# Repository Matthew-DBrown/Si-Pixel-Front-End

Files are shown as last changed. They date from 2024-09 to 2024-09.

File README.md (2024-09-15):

# Si-Pixel-Front-End
A pulse shaping front-end from discrete, off-the-shelf components for a diode acting as a pixel for particle detection. 
The front-end circuit alone is considered here.

This project project investigates the feasibility of using a diode as a pixel, where its depletion width is the active region where particles may interact, such as cosmic rays.
The output from the diode is expected to be a sharp current pulse that needs to be shaped to be digitally counted. This calls for the design of a front-end pulse shaping circuit for which the KiCad files and outputs can be seen in this project.

Included files:
- KiCad Schematics
- PCB Layout (future proposals)
- Breaboard and waveform images

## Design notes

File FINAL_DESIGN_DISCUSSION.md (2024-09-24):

## Analogue Front-End Components
### Integration and Initial Shaping

The first stage of the analogue front end is to integrate the input charge with an active integrator. As established, the input signal must be amplified, and the integrator can achieve this
with RC values less than unity, according to,

$` V_{\text{out}} = -\frac{1}{RC}\int V_{\text{in}}\,dt`$.

The input charge will be proportional to
the energy of the detected particle, hence the integrator’s importance in particle identification.
The choice of capacitance is informed by the total charge injected from the simulated imput pulse. The
current can be obtained by dividing the equation of the simulated input,

$` V_{in}(t) = A\left\{\exp\left(-\frac{t}{\tau_1}\right) - \exp\left(-\frac{t}{\tau_2}\right)\right\}. `$,

with the resistance through which the the pulse will travel after being emitted by the diode. To generate the simulated pulse in reality, a test capacitor will have to discharge through a resistor to create the exponential envelope desired. An arbitrary value resistance is chose here, at 18 Ω, and the simulated pulse is apprxoimately 100 ns in duration as seen in the theory file. The charge injected into the circuit can be estimated by integrating the current over the pulse width, T = 100 ns,

$` Q_{\text{tot}} = \frac{1}{R}\int_{0}^{T} V_{\text{in}}\,dt\approx92\times10^{-15}\, \text{C} `$.

The op-amps and buffers discussed in the desin considerations operate at ±5 V which is therefore the
maximum output magnitude of the integrator. A small voltage drop would be seen such that
the true maximum output is slightly less, hence the capacitor value is chosen from Q/V , with
V slightly below 5 V. This means using a small ~25 ×10−15 F capacitor would be favourable,
with SMD models meeting this criteria. The small capacitance results in a short time constant,
meaning the integration is performed rapidly, creating a step-like output at the integrator.

To set the pulse width after the integrator, a high-pass CR filter follows, isolated by a buffer.
A decay constant is introduced, such that the pulse width is reduced to approximately five time
constants (where one time constant, τ is 320 ns in this design) of the CR filter, assuming that
the integration time is negligible [^1]. The integrator’s capacitor must fully discharge before another pulse from the diode arrives, since any remaining charge will introduce an offset on the integrated pulse and hence the output, providing artificially high voltages, and false particle identification. Placing a resistor in parallel with the integrating capacitor provides a controlled discharge path. It must have sufficiently large resistance such that on the time scale of the input pulse, the decay of the capacitor is negligible, and remains to appear step-like.

For the same reasons discussed in the theory section, the profile of the high-pass filter output is not
practical since the maximum amplitude is sharp and short in duration after introducing a decay
tail to the step input from the integrator. A low-pass filter is therefore introduced, with the
same time constant as the high-pass filter; these stages in addition to their outputs are illustrated below along with their Fourier transforms. 

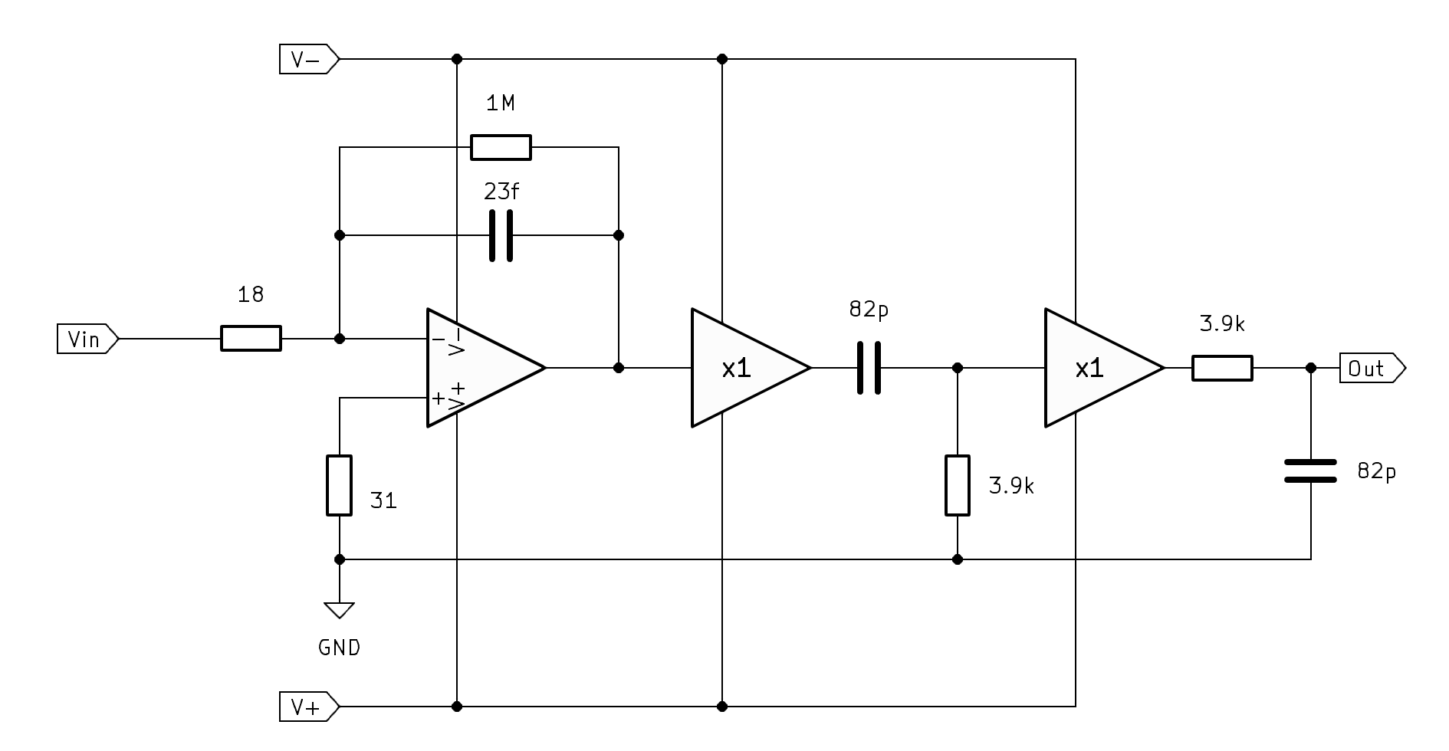
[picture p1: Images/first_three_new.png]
Schematic of the first three components; the integrator, CR filter and RC filter.
|  |
|:--:| 
| KiCad schematic design of the first three components; the integrator, CR filter and the RC filter. |

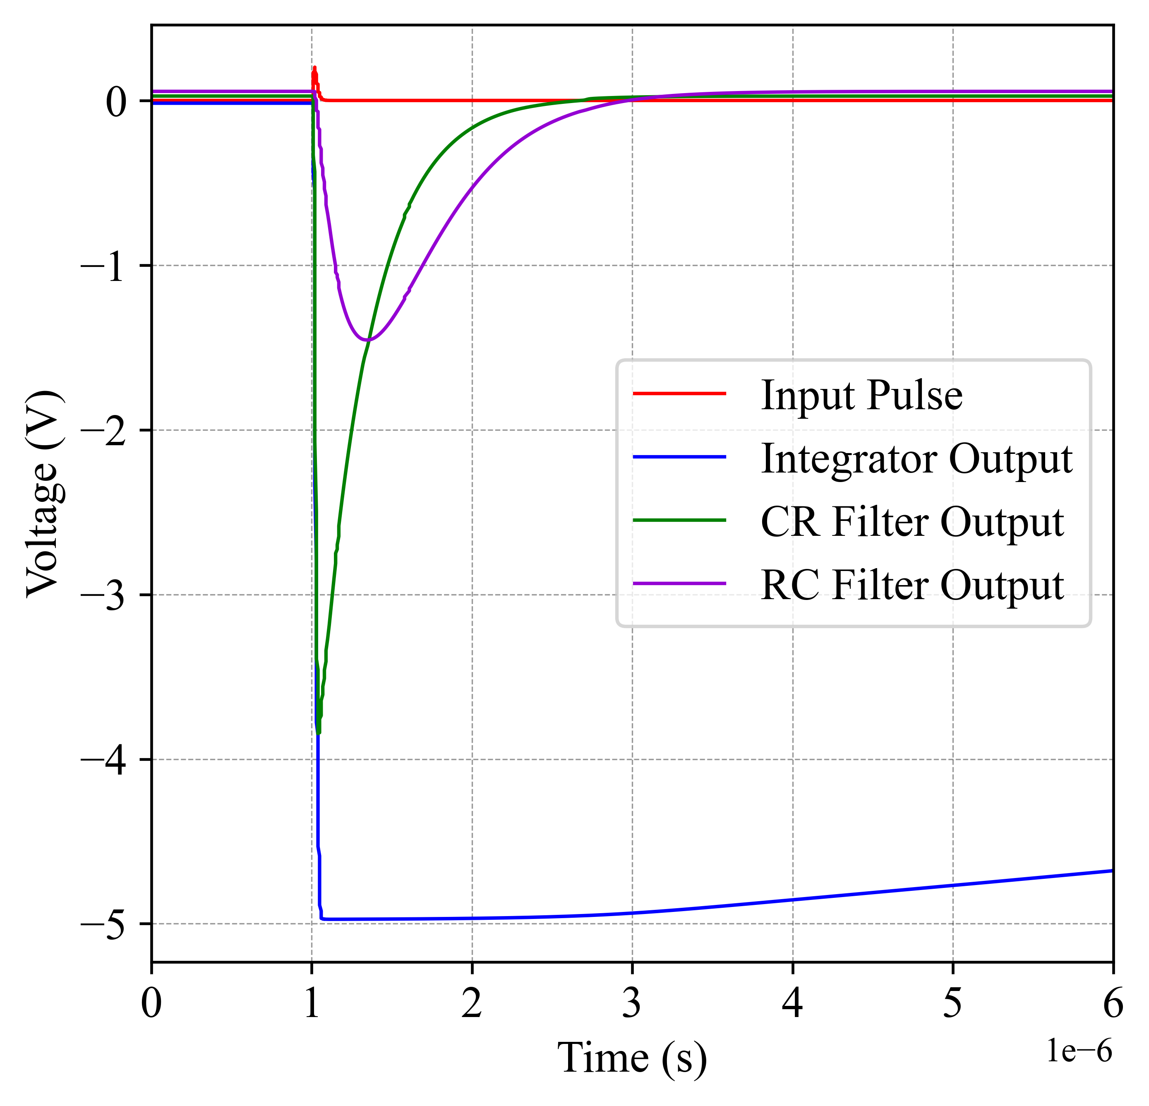
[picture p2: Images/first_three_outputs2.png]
Simulated output voltage signals for the first three stages of the design
|  |
|:--:| 
| Simulated output voltage signals for the first three stages of the design. The discharge of the integrator is slow, and its output appears step-like on the time scale of the input pulse. The CR filter sets the pulse width. |

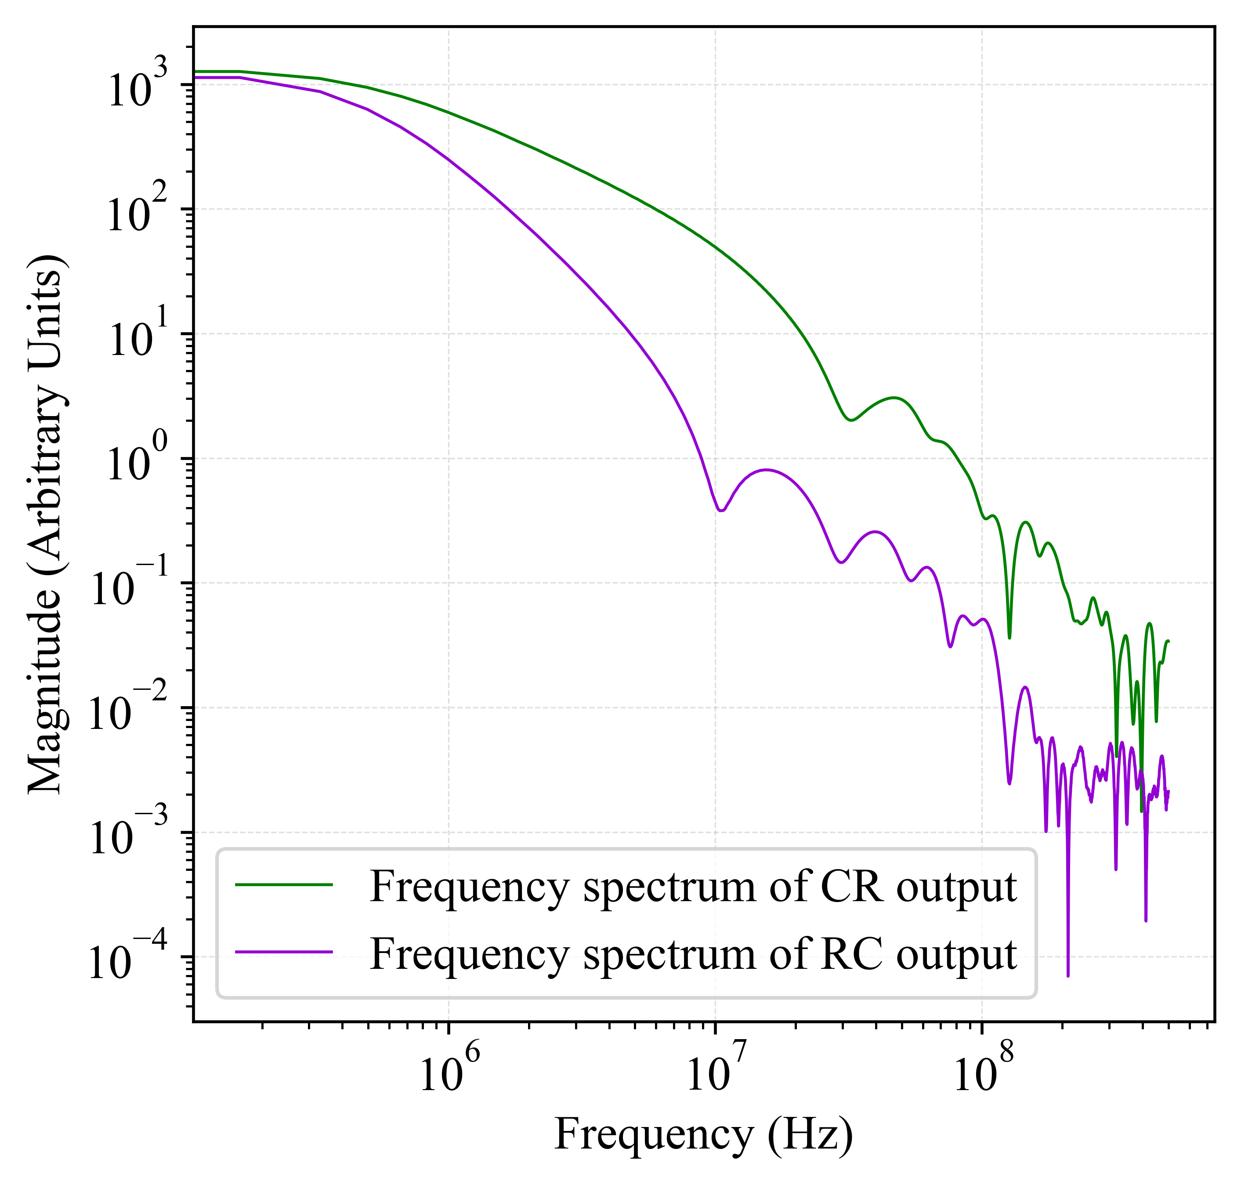
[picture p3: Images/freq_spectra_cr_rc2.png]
Fourier transforms of the outputs of the CR and RC filters
|  |
|:--:| 
| Frequency spectra of the CR and RC filter outputs of the figure above. A larger dominance of lower frequency components is seen after passing through the low-pass, RC filter, broadening the sharp pulse outputted from the CR filter. |

As expected, the CR filter output has high frequency
components due to its sharp nature. These components are attenuated by the RC filter, where
their relative magnitudes drop by several orders at frequencies above 10 MHz, whilst the lower
frequency components are mostly unaffected and hence their more dominant contribution. It
is for these reason that the output becomes more smooth, since the reduced noise bandwidth
in the frequency domain results in an increased pulse width in the time domain from Fourier
theory [^2]. This further results in high frequency noise mixtures being attenuated early in the
circuit before propagating to the final output.

## Multiple Low-Pass Filters
The signal-to-noise ratio (SNR) at the output of the RC filter can be further improved with
multiple low-pass filters in series with equal time constants, τ [^3][^4]. The choice of having
equal τ across all filters is not only for simplicity, but is also for symmetrical shaping, where
the output after each subsequent RC filter becomes more Gaussian, as demonstrated below.
It is this waveform that has the best SNR. The number of low-pass filters following the
high-pass filter has a direct effect on the length of the pulse, as the peaking time, the time taken
to reach the maximum amplitude, is given by the number of RC filters, multiplied by the time
constant, set at 320 ns. Simulations demonstrate that using more than four RC filters yields
diminishing returns since the form of the output is negligibly different from a true Gaussian at
this point, and the noise bandwidth reduction significantly slows down, as seen in the Bode plots below.

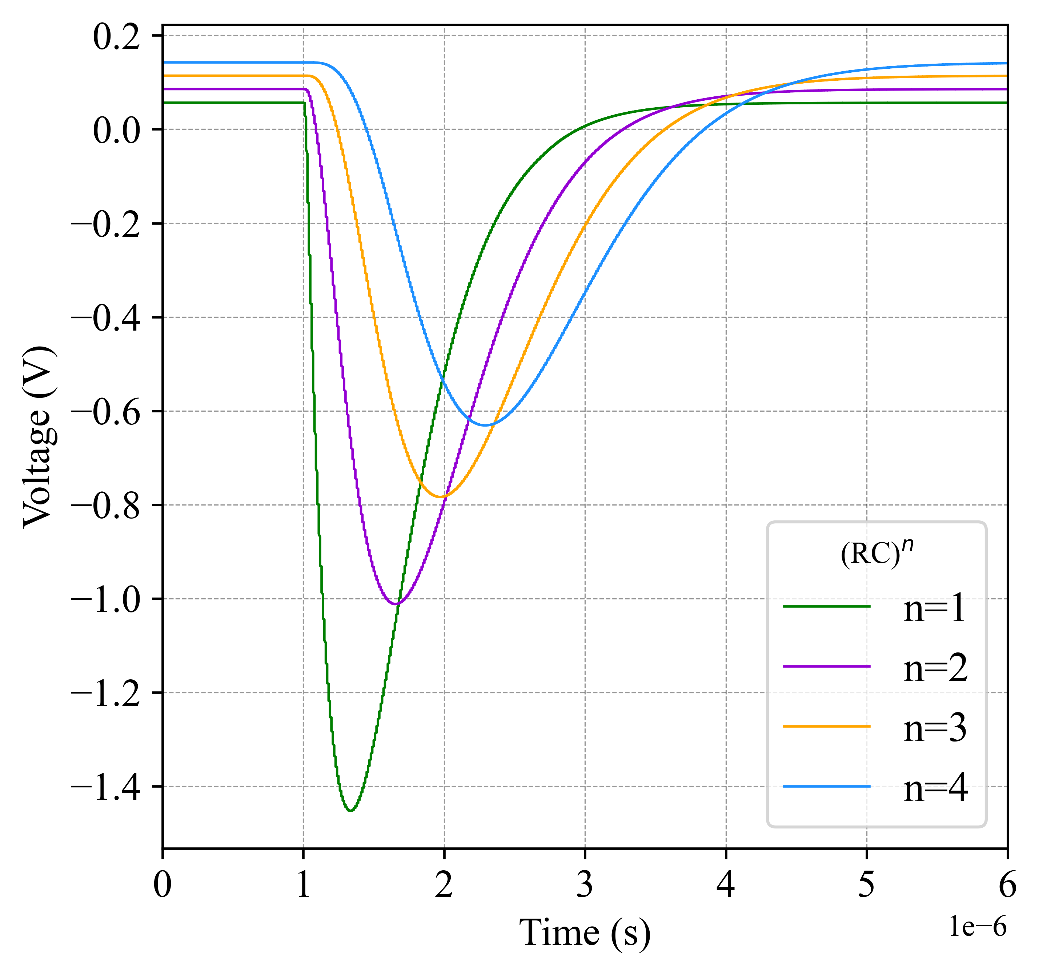
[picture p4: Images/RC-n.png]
Output signal after repeating RC sections becoming more Gaussian.
|  |
|:--:| 
| Output signals of $` (RC)^n `$ for the CR input, with improved SNR with increasing n. The sharp peak input is smoothened as expected from Fourier theory. |

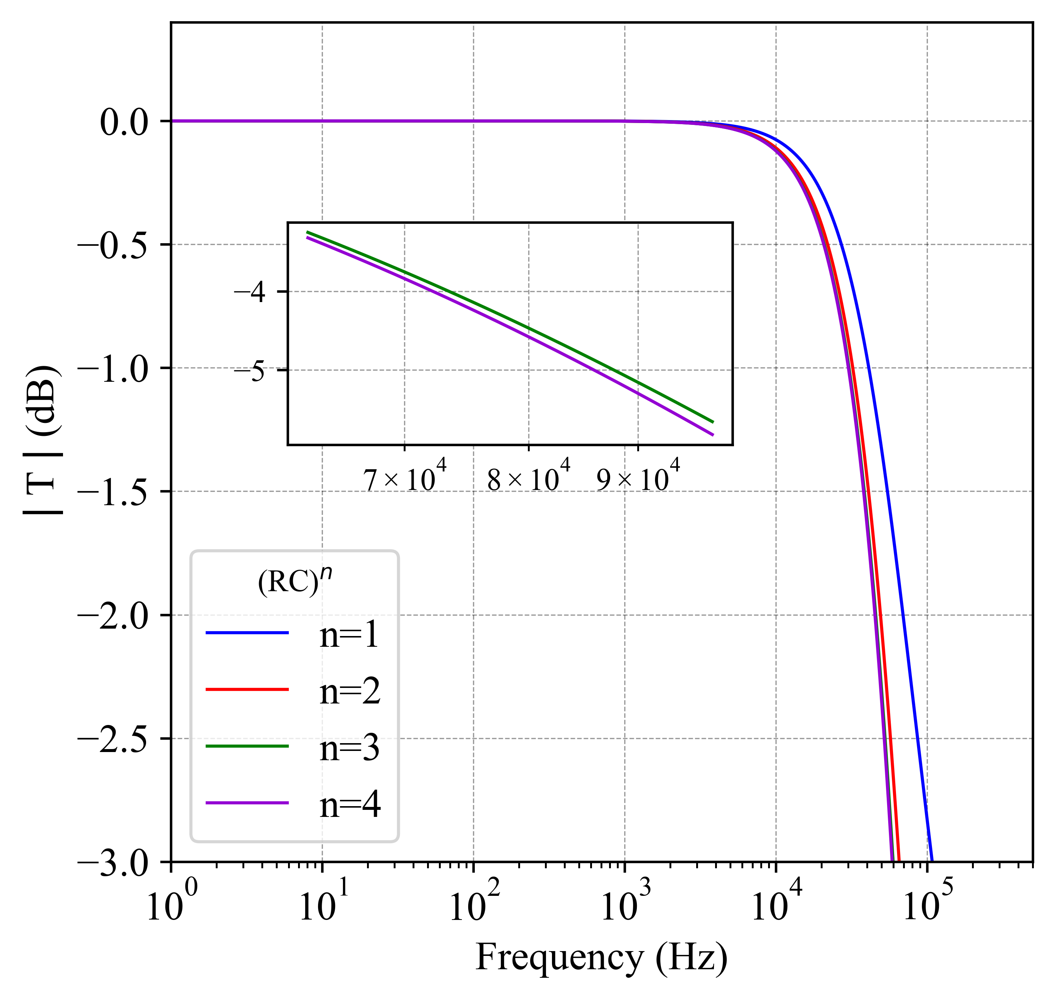
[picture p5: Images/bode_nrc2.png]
Output signal after repeating RC in the frequency domain.
|  |
|:--:| 
| Bode plots for $`n`$-RC filters, showing little change in frequency bandwidth between the third and fourth filter, with the latter curves almost entirely superimposed. |

The peaking time, from transient simulation data, was found to match closely with the
expected times for different n, with the largest deviation seen being 20 ns from the expected
320 ns after one RC filter. Since no trend was found in the slight deviations between expected
peaking times after n filters, the small discrepancies have been attributed to sampling intervals
in KiCad; it is likely that the true peaking times lie between two time steps.
Overall, one sees predictable peaking times, and how the pulse width can be increased to
comply with the parameters of the digitisation components. The pulse width of the output
from the fourth low-pass filter is estimated to be 5.60 ± 0.05 μs. If perfectly Gaussian, the
peaking time would be half the pulse width at 2.8 μs, which is larger than observed. This
further illustrates a slight deviation from a Gaussian waveform, however, it is suggested from
extended simulations that any further filtering would be more detrimental due to larger losses
in pulse height, increasing later amplification requirements.

## Inversion and Offset Removal

Since the integrator at the first stage is inverting, this must be corrected by an inverting op-
amp. Its optimum placement is at the end of the pulse shaping circuit, for best signal output,
since the frequency response of the LMH6611 diminishes with increasing closed-loop gain [^5].
After passing through multiple low-pass filters, the main frequency composition will now be on
the order of hundreds of kHz to MHz, as illustrated below.

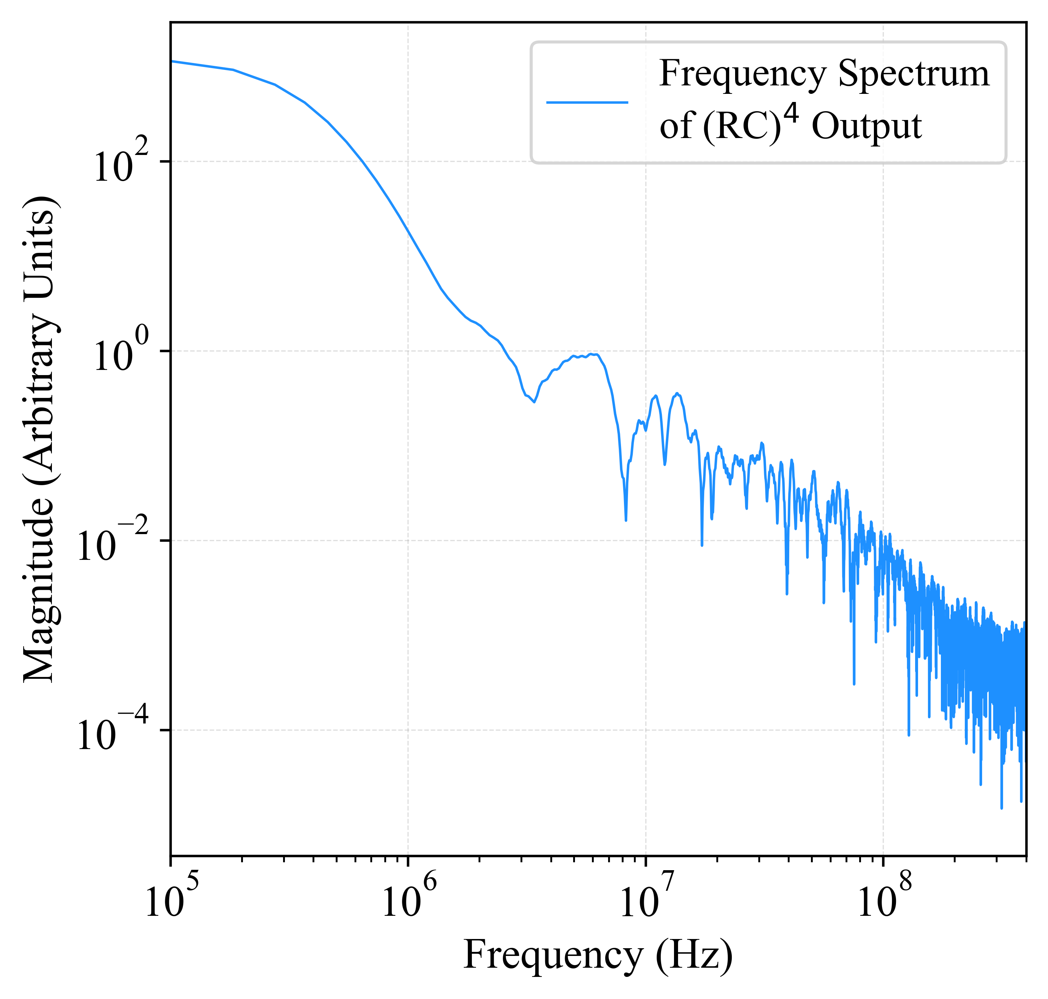
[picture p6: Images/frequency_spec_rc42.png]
Frequency spectrum of the signal after four RC filters.
|  |
|:--:| 
| Frequency spectrum of the signal after four RC filters. |

In an inverting configuration, the LMH6611 has a 0-dB bandwidth around 100 MHz for closed loop gains between -2 and -5.
The output signal from the low-pass filters is therefore comfortably within the frequency range
for well-behaved amplification; this would not be true for the signal before the RC filters.
The figure below illustrates an accumulating offset at the output. A summing amplifier is therefore to be introduced after the inverter to
remove any final offsets. The likelihood is that the offset seen in a realised circuit would be
different to that simulated, and hence the choice of resistor values for the summing amplifier
would be based on empirical observations.

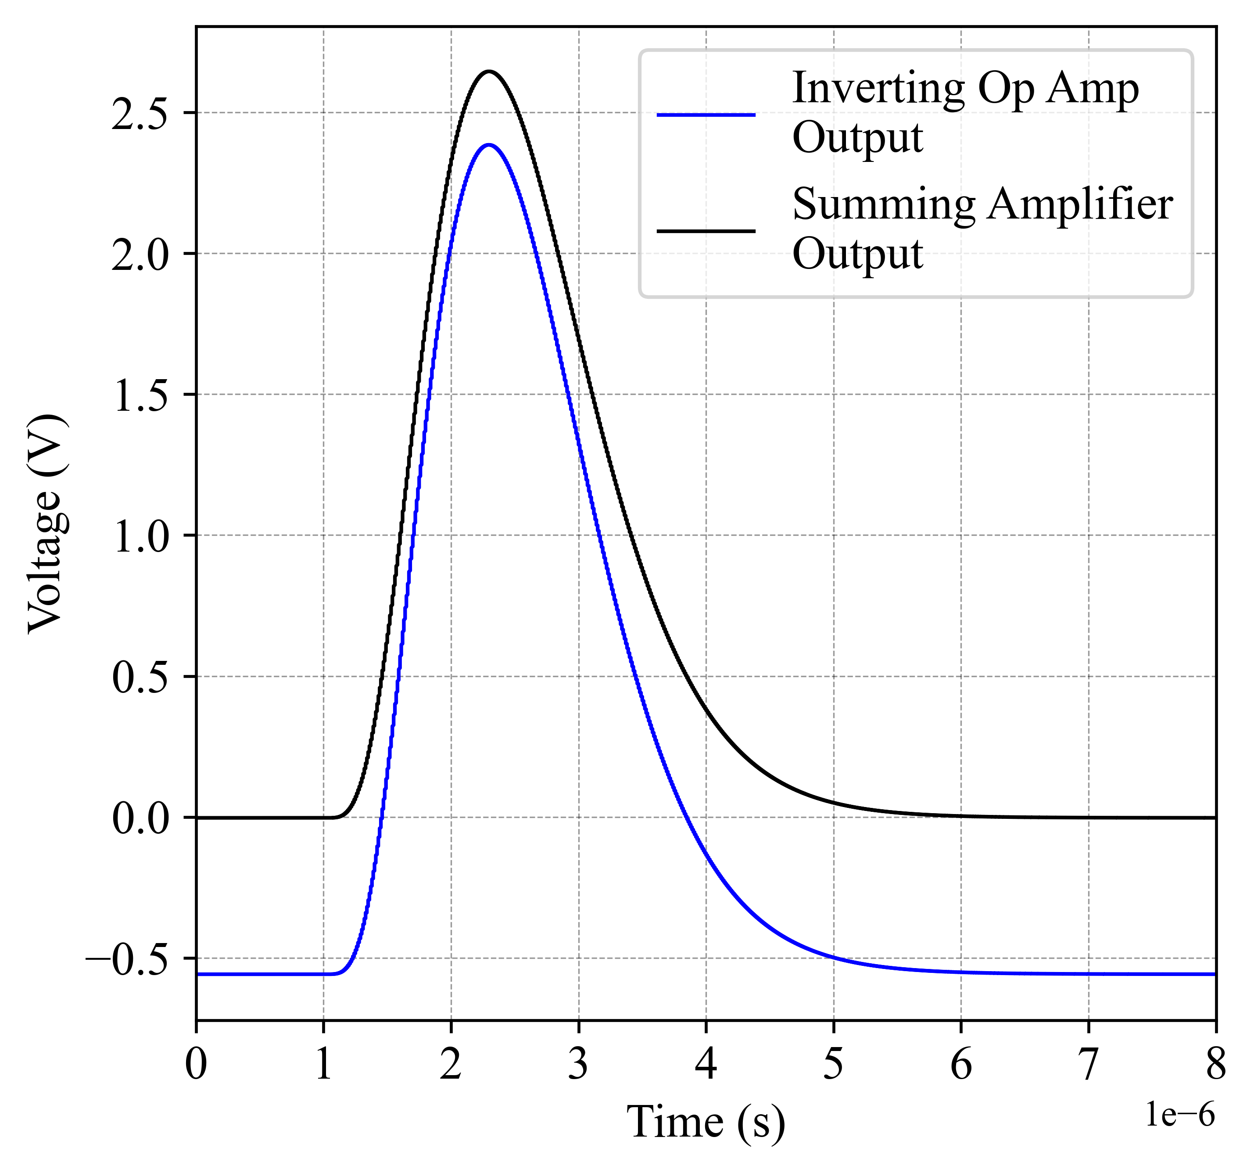
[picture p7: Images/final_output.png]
Demonstration of offset removal of the output pulse using a summing amplifier.
|  |
|:--:| 
| Final output after inversion and offset removal. |

## Full Design

Below is the full design brining together the components discussed above.

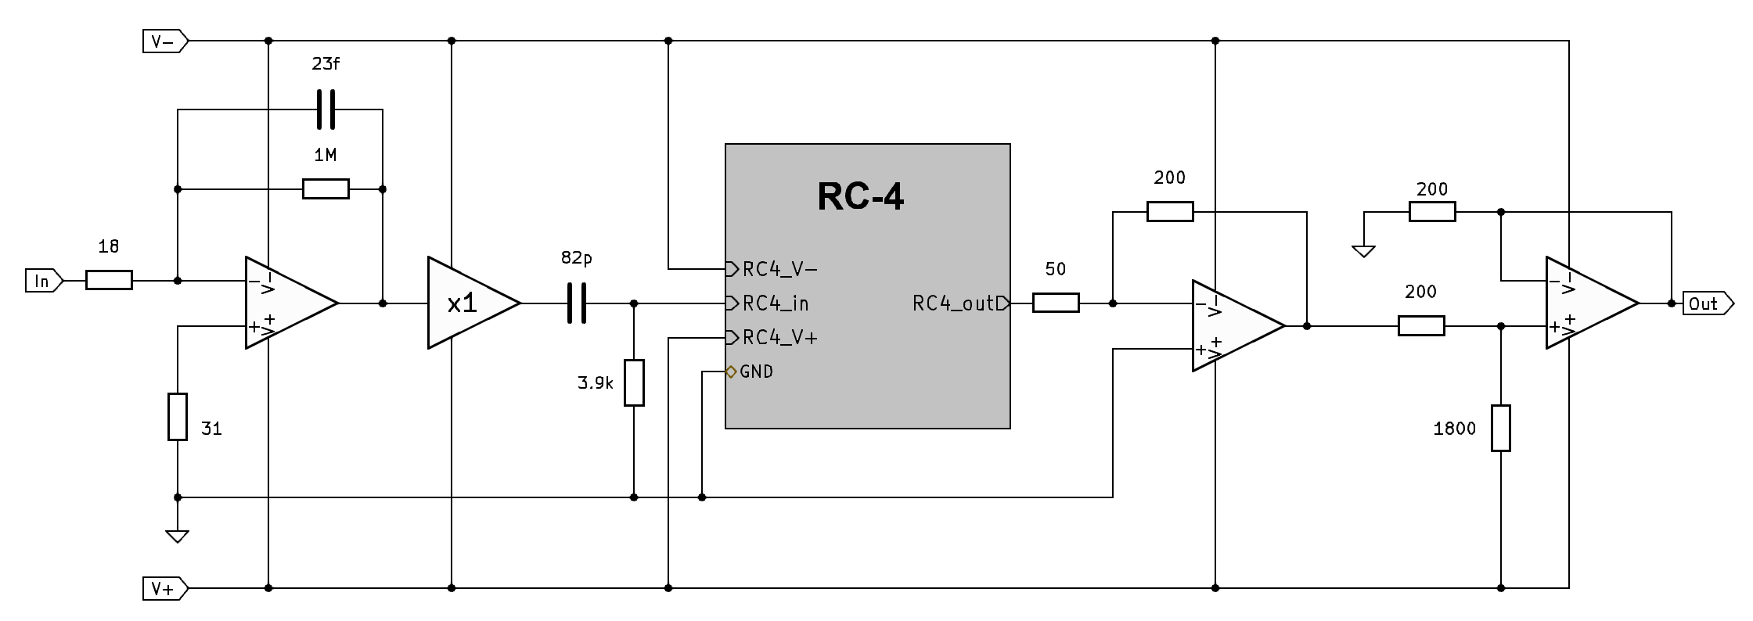
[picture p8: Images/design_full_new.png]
Full front-end design schematic from KiCad
|  |
|:--:| 
| Full design with four low-pass filters (RC-4), followed by an inverting amplifier with a gain of four, and a summing amplifier at the end to remove offset accumulation. Practical adjustments to the integrator include the parallel discharge resistor and non-inverting input resistance to reduce the output voltage offset [^6]. |

## Footnotes

[^1]: Shenkman AL. Transient analysis of electric power circuits handbook. Springer Science &
Business Media; 2006.

[^2]: Hoffman F. An introduction to Fourier theory. Extraído el. 1997;2.

[^3]: Knoll GF. Radiation detection and measurement. John Wiley & Sons; 2010.

[^4]: Spieler H. Semiconductor detector systems. vol. 12. Oxford university press; 2005.

[^5]: Instruments T. LMH6611/LMH6612 Single Supply 345 MHz Rail-to-Rail Output Am-
plifiers; 2013. Available from: https://www.ti.com/lit/ds/symlink/lmh6611.pdf?ts=
1710012404970.

[^6]: Sedra AS, Smith KC. Microelectronic Circuits. 5th ed. Oxford University Press, Inc., New
York; 2004.

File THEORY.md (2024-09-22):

# Overview of Theory

## The Diode Pixel

Under reverse bias, a diode will output current when a charged particle traverses through the depletion region, though in reality, this is difficult to set up. A depletion length must be sufficiently wide that when multiple diodes are used, the probability of a particle interacting is non-negligible. A potentially suitable diode is a Zener diode which handles reverse breakdown voltage without damage and conducts a sizeable amount of reverse current. Below is a typical illustration of a diode under reverse bias with a depletion width in the centre.

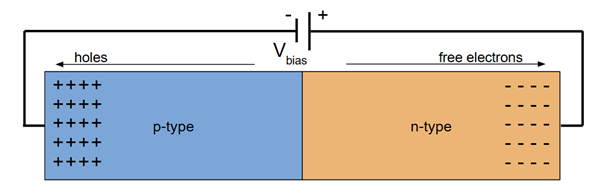
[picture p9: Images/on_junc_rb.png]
Reverse biased diode schematic image


A depletion width is seen in traditional CMOS technology used in advanced particle detectors. The image below from 'Microelectronic Circuits' by Sedra/Smith illustrates the depletion region seen in NMOS transistors.

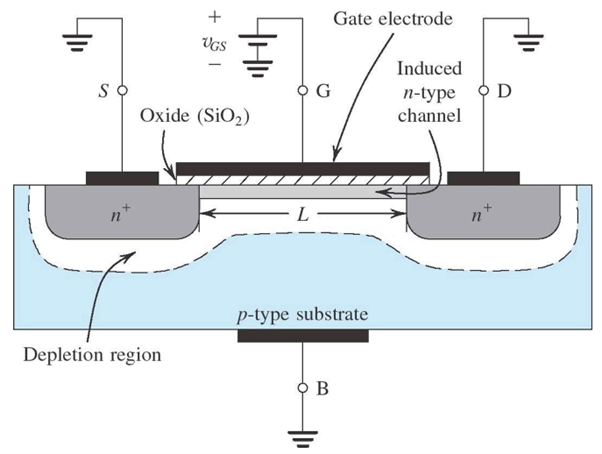
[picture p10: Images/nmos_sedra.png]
NMOS schematic image


The schematic below simply illustrates how a charged particle passing through the depletion region generates electron-hole pairs through the ionisation of electrons to the conduction band. A detectable current is achieved that is short in duration due to the small size of the system.

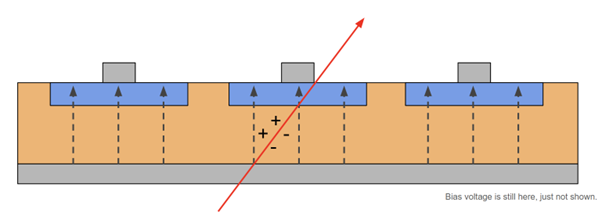
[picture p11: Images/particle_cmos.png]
Detection_schematic image


## The Front-End 

The front-end pulse shaper is needed to take the sharp output and transform the waveform into something measrable by a counter at the end which may, for example, detect the rising and falling edges of digital signals. The fundamentals of what the front-end should do is shown in 'Semiconductor Detector Systems' by Helmuth Spieler with the bassic schematic outline illustrated below.

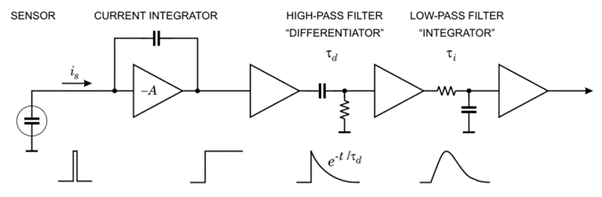
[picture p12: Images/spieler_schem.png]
Detection_schematic image


## Assumptions and Design Considerations

Before designing the circuitry, a representation of the output from the diode (current pulse) to the front-end must be established. The depletion width of a diode essentially contructs a capacitor system and so the output of the diode is expected to decay with an exponential waveform. Similar waveforms can be seen in other detector systems, such as the pulses from the anode in photomultiplier tubes. In reality, there is also a rise time to the pulse before the exponential decay commences which slightly reduces the sharpness of the pulse output from the diode. Considering all these factors, the following waveform is appropriate,

$` V_{in}(t) = A\left\{\exp\left(-\frac{t}{\tau_1}\right) - \exp\left(-\frac{t}{\tau_2}\right)\right\}. `$

A plot of this waveform is shown below, constructed in Python. The pulse is 100 ns in duration with a peak voltage around 200 mV.

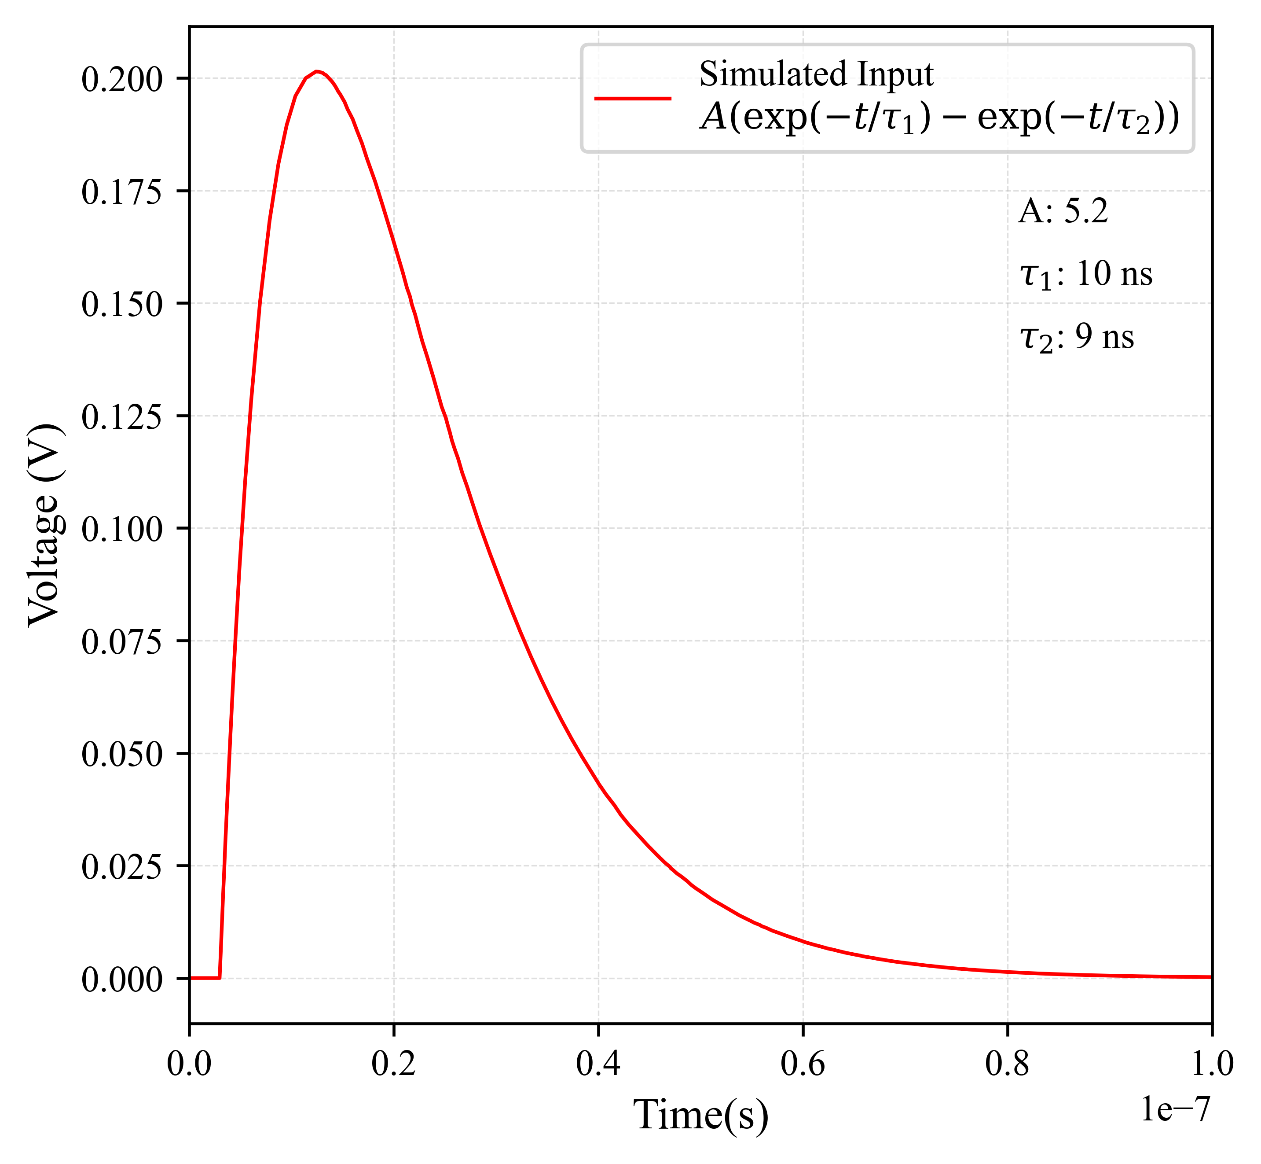
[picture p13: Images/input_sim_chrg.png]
Simulated_pulse plot


The analogue front-end shaping circuit must amplify the input signal to a measurable output
level, preferably on the order of volts, compared to the low mV range at the input. Practically,
this would allow for higher voltage thresholds to be set at the digitisation stage when outputting
high or low signals, which are easier to implement with potential dividers. Key characteristics
such as time over threshold would also be more easily determined due to a lesser influence of
noise. The time over threshold further encodes information regarding the particle that is detected, though this is currently beyond the scope of this project.

Sharp peaks, as seen in the simulated pulse above, are difficult to process since the maximum amplitude
is not maintained for a relatively long time [^1], hence the pulse should be widened such that
it is smoothened at the peak. The limit on the shaped pulse width should be determined by
the environment in which it will be used, since a pulse width longer than the time interval between subsequent detections would introduce stacked pulses and the need for deconvolution
post-processing, as demonstrated by E.M. Khilevitch et al. [^2].

An additional consideration is the slew rate of op amps. The internal structure of op amps
typically includes a compensation capacitor which reduces the unity-gain bandwidth such that
phase shifts occur beyond this frequency, outside the ideal operating parameters of the op amp
[^3]. This along with other phenomena introduce a slew rate, the upper limit on the rate of
change of the output. If the rate of change of voltage at the input signal is greater than the
op amp slew rate, the output rate of change of voltage would be restricted to the slew rate,
which causes distortion and an undesired increase in signal length. The expected input described above sees a rapid change of voltage with time, approximately 20 V/μs, and hence has high frequency components that would be seen from Fourier transforms. This leads one to immediately disregard some of the most common op amps such as the LM741 with a slew rate of 0.5 V/μs and a
1.5 MHz bandwidth [^4]. An op-amp that could be used in this project is the LMH6611 with a 0.1-dB
bandwidth of 45 MHz and a slew rate of 460 V/μs [^5]. This slew rate is sufficient for the simulated pulse above, yet may fall short when accepting the true diode signal which is currently unknown. Faster op amps such as
the OPA818 would excel, however their package form makes prototyping difficult, hence their
omission [^6].

Pulse shaping circuits typically include multiple RC or CR sections, each contributing to
alter the decay and rise times of the output. Each section can load the next if not separated by a
buffer [^7]. Op amps may be used as buffers in the source follower configuration,
however these can introduce distortion and hence noise on the output, especially if they are not
unity gain stable [^8]. It is therefore proposed that dedicated buffers are used instead, again
with sufficiently large bandwidth and slew rate. Exceeding this criteria is the BUF602, with a
1 GHz bandwidth and an exceptionally high slew rate of 8000 V/μs [^9].

## Footnotes
[^1]: Knoll GF. Radiation detection and measurement. John Wiley & Sons; 2010.

[^2]: Khilkevitch EM, Shevelev AE, Chugunov IN, Iliasova MV, Doinikov DN, Gin DB, et al.

[^3]: Horowitz P, Hill W, Robinson I. The art of electronics. vol. 2. Cambridge university press
Cambridge; 1989.

[^4]: LM741 data sheet, product information and support | TI.com; 2024. (Online; accessed 14.
Mar. 2024). Available from: https://www.ti.com/product/LM741.

[^5]: LMH6611 data sheet, product information and support | TI.com; 2024. (Online; accessed
14. Mar. 2024). Available from: https://www.ti.com/product/LMH6611.

[^6]: OPA818 data sheet, product information and support | TI.com; 2024. (Online; accessed
14. Mar. 2024). Available from: https://www.ti.com/product/OPA818.

[^7]: Mancini R. Op amps for everyone: design reference. Newnes; 2003.

[^8]: Carter B. Op amps for everyone / Bruce Carter, Ron Mancini. Fifth edition. ed.; 2018.

[^9]: BUF602 data sheet, product information and support | TI.com; 2024. [Online; accessed
14. Mar. 2024]. Available from: https://www.ti.com/product/BUF602.

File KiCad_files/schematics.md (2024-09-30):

This folder contains KiCad schematics and the evolution of the design. Some of the files contain duplicates of the same circuit with different opamps to test and compare their suitability.

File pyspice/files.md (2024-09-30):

These are pyspice models for the components of the KiCad obtained from Texas Instruments online. The zip files are included for convenience.

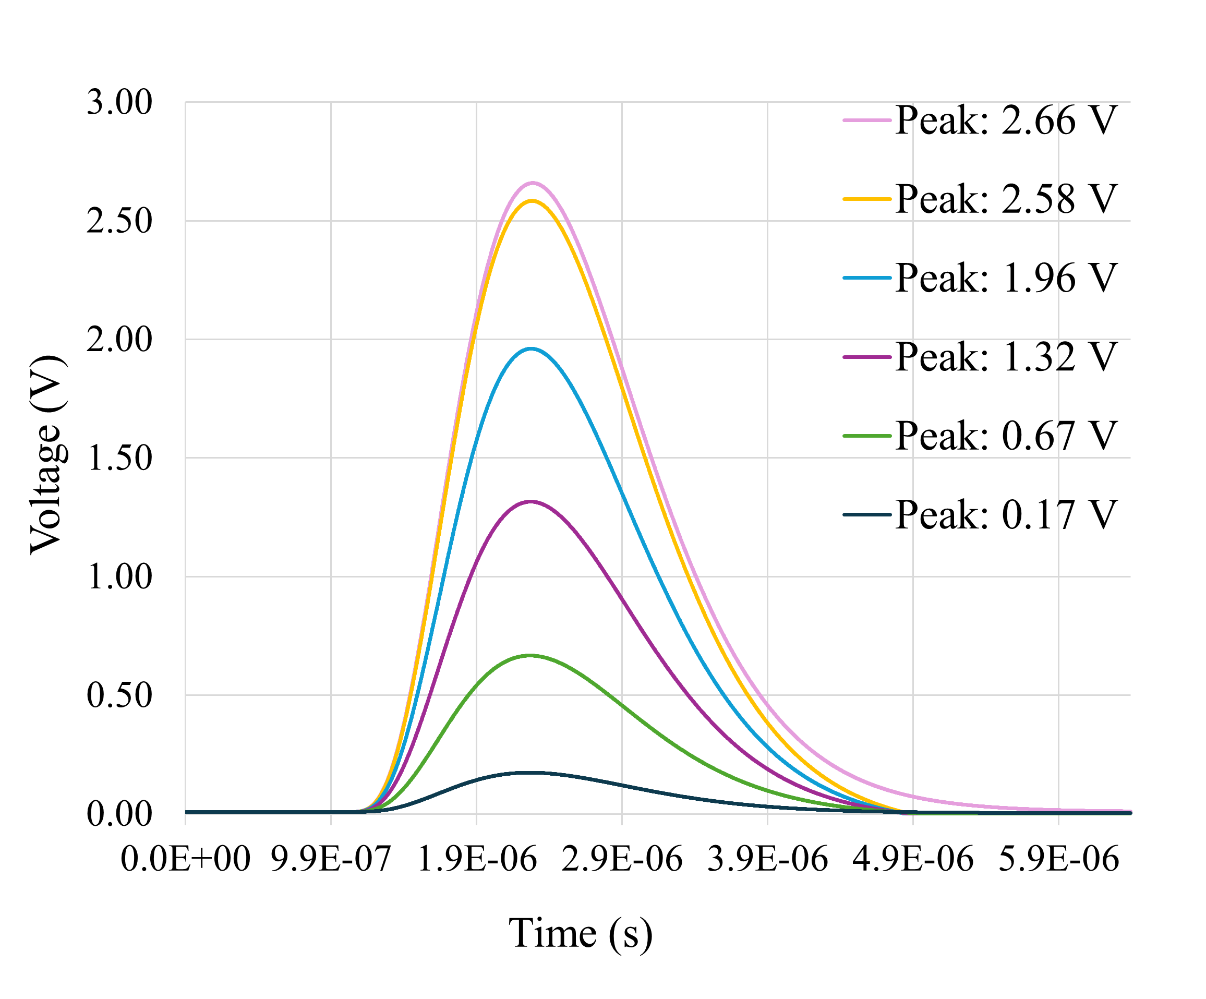
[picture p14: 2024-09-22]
Images/pulse_widths_output2.png

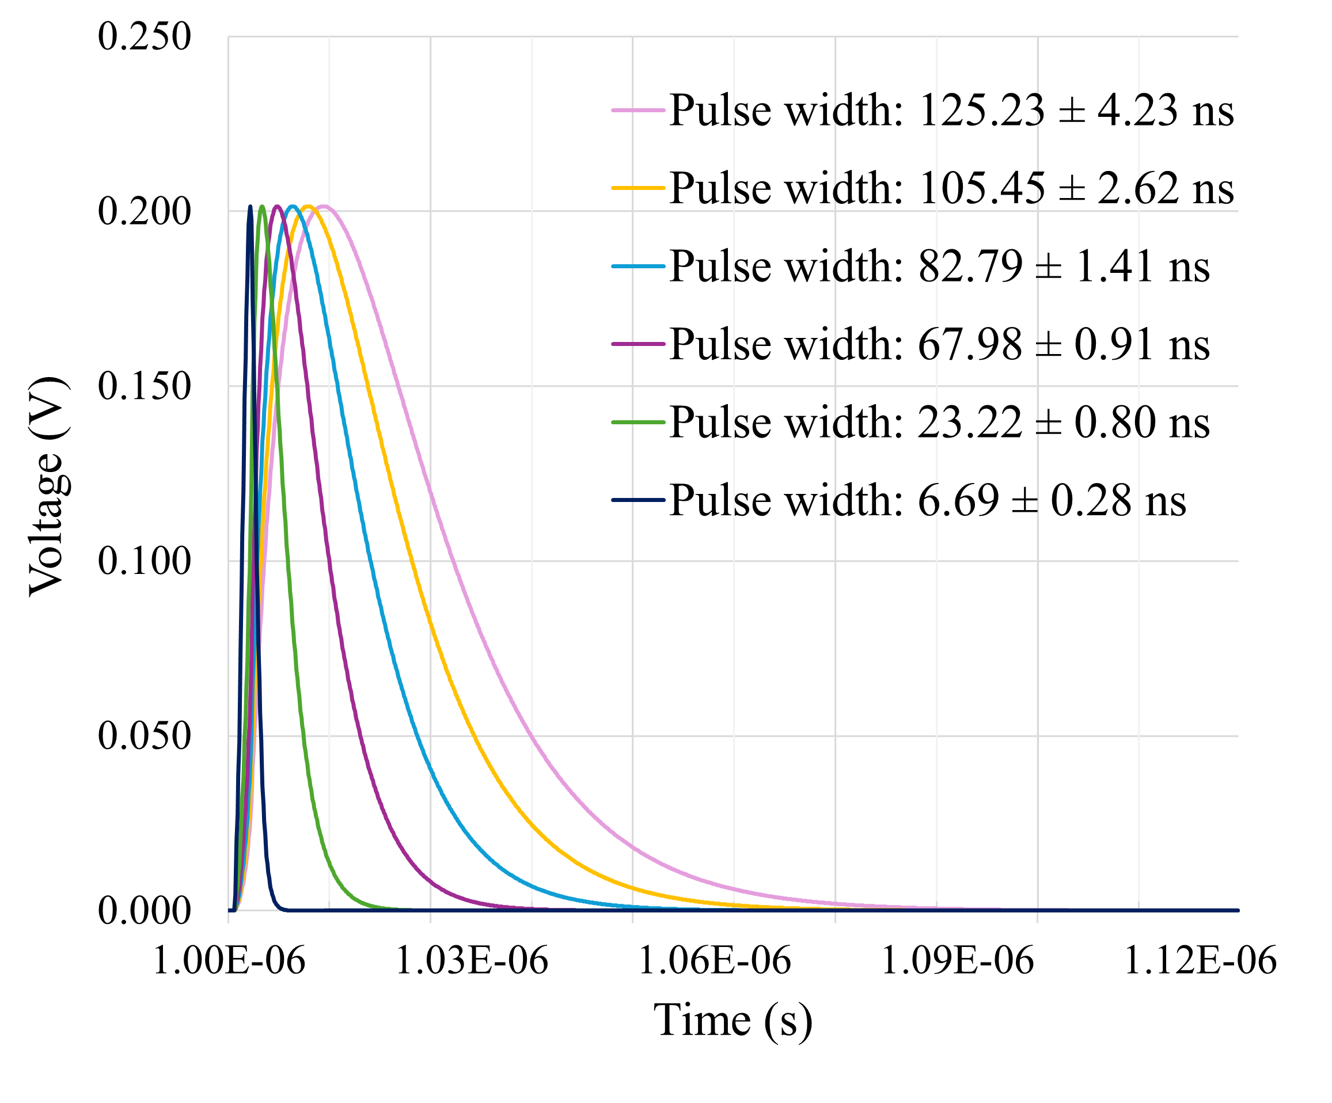
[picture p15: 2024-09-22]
Images/pulse_widths4.png
